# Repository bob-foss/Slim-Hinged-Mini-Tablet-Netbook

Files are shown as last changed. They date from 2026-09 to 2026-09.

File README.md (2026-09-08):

## Slim Hinged Mini Tablet Netbook

Edit: [Featured on Hackaday!](https://hackaday.com/2026/09/08/old-ipad-keyboard-makes-for-a-modern-netbook/)

This is a simple netbook project revolving around a ZAGG keyboard-case. With this adapter, you can take any mini tablet (about 8 inches diagonally) and make it a functional netbook by combining it with a [ZAGG 5th Gen iPad mini case](https://www.ebay.com/itm/296127718453). ZAGG keyboard-cases are special due to their actual metal hinges (which are unusual for tablets), allowing you to adjust the angle while it sits on your lap. They are also quite affordable. The result is a handsome netbook which makes a satisfying snapping sound when it closes. 

Measurements for the STL were done by hand. Half millimeter adjustments may be necessary. 

### A simplified list of instructions. 
1. Open up the black plastic hinge cover on the ZAGG keyboard-case to expose the metal hinge underneath.
2. Unscrew the screws. You may need to use a rubber band for extra friction, the screws strip easily.
3. 3D print a case for your tablet with the adapter attached.  
4. Attach the screws, nuts and washers and you're done! Pair the Bluetooth keyboard and you're all set!

### Detailed list of components
- The included adapter STL
- 3D print filament
- 6 m2 screws, nuts and washers
- 1 small form factor tablet, around the size of an iPad Mini 5th gen
- 1 [ZAGG Keyboard Case for a iPad Mini 5th Gen](https://www.ebay.com/itm/296127718453)
- 1 STL file for a case

### Pictures and explanations
1. This is the keyboard/case without the black plastic covering taken off (a quarter for scale).
   - 
   - 

2. This is the black plastic hinge cover to take off.
   - 

3. This is how to pry the black plastic hinge cover off.
   - 

4. This is the keyboard/case with the black plastic covering taken off.
   - 

5. This is the keyboard/case without the screws.
   - 

6. This is the case I'm choosing for my model (Lenovo Legion Y700). [Link to cults STL file](cults3d.com)
7. This is me using Tinkercad to add the adapter STL to the case.
   - 

8. This is the completed adapter STL + case (plus a few minor changes).
   - 

9. This is me installing the new case.
   - 
   - 

10. This is it all done!
   - 

### Recommendations and Ideas
- Try TPU for the case for impact protection. If you do, I recommend a high infill especially for the adapter itself.
- Some tablets in this form factor accept a SIM card, so you can take calls from this set up!
- Here's a sample Android config:
  - [Key Mapper](https://github.com/keymapperorg/KeyMapper)!
    - One of my favorite apps. Really kicks the usefulness up a notch. It turns this from "Here's a tablet with a keyboard" to "Wow, I could actually get some work done with this."
  - Kiwi Browser + your favorite desktop extensions
    - [uBlock Origin](https://github.com/gorhill/ublock)
    - [Vimium](https://github.com/philc/vimium)
    - [TK's Tree Style Tab Outliner](https://github.com/ToyKeeper/tktsto)
  - [Termux](https://github.com/termux)
  - WPS Office/Google Docs
  - Obsidian
- I do not recommend opening up the keyboard itself. It's held together by glue and little plastic clips. Opening it up *will* break the plastic clips and it does not come back together. 

### Final Thoughts
- This project is a way to turn lightweight tablets into decently portable & effective computers.
- I do not claim that this is groundbreaking work. This project makes me feel like the first person who taped a camera to a cell phone and called it a cameraphone.
- If you want more power in a small form factor, you might also be interested in [MysteriousAlarm897's work]([url](https://www.reddit.com/r/LegionGo/comments/1mvnv84/converting_a_legion_into_a_laptop/)) on doing something similar with a Lenovo Legion Go. Their first version included space extra batteries, but they also made a slimmer version.
  - Mine is still skinnier though, lol.

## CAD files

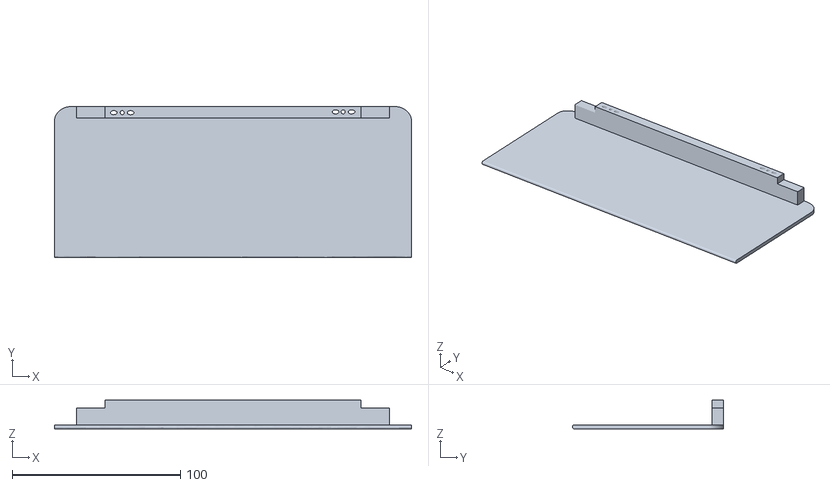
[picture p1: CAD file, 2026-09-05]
Zagg Adapter for the iPad Mini 5th Gen Hinge.stl
212.5 x 90.0 x 17.2
